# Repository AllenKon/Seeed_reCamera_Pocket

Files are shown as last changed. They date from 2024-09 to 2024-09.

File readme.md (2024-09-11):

**The project contains the 3D housing and circuit design files of the reCamera Pocket.**

🎈🎈🎈🎈🎈🎈🎈🎈🎈

## reCamera Pocket



The reCamera Pocket is a portable charging device for reCamera, available in two models, vertical and horizontal.

The STL file for printing is at the URL: https://makerworld.com/zh/models/634900

Picture should be here.

### Horizontal

Horizontal compatible with standard version of reCamera.

### Vertical

Vertical needs to be replaced with a B2 base plate and replace the retainers on the bottom of the reCamera.

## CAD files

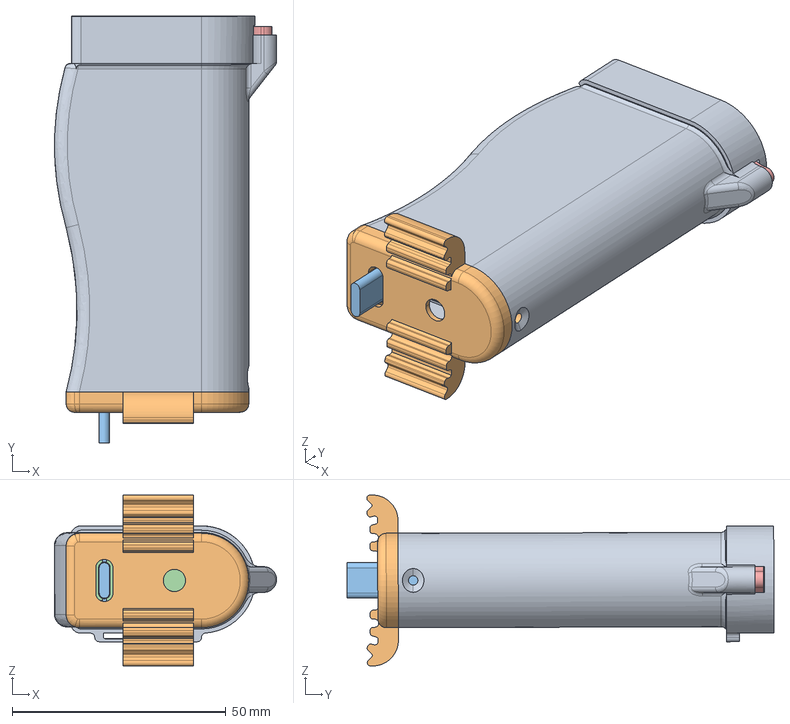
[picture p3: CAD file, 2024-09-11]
Model/reCamera_Pocket_Horizontal.stp
52.0 x 99.9 x 40.0 mm
BATTERY_SHELL
TOP_SHELL
TYPEC_BOARD
4000MAH_BATTERY
BOTTOM_SHELL

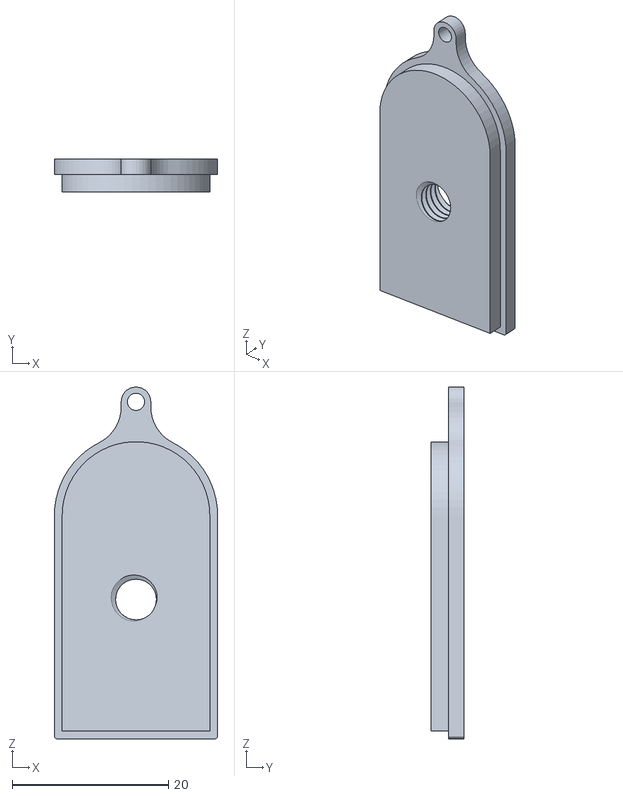
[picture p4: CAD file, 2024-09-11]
STL/reCamera_Pocket_Shell_Bottom.stl
20.9 x 4.20 x 45.1

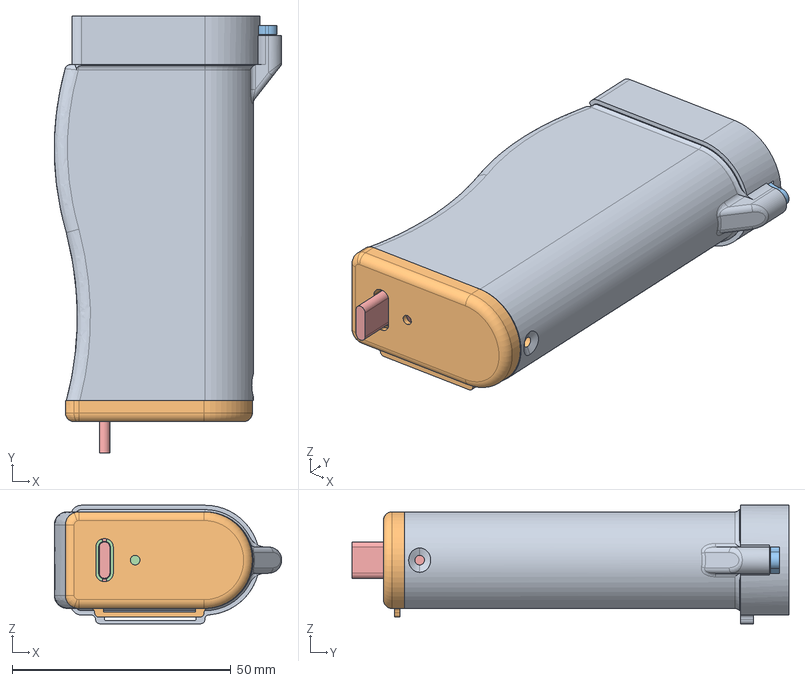
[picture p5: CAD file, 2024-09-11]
Model/reCamera_Pocket_Vertical.stp
52.0 x 99.9 x 27.1 mm
BATTERY_SHELL
VERTICAL_SHELL
BOTTOM_SHELL
4000MAH_BATTERY
TYPEC_BOARD

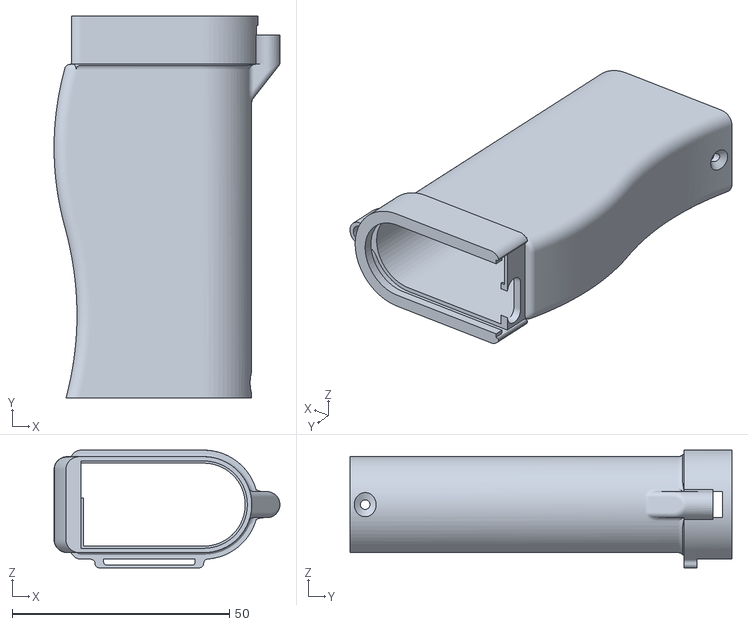
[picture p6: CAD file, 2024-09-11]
STL/reCamera_Pocket_Shell_V.stl
52.0 x 87.9 x 27.1

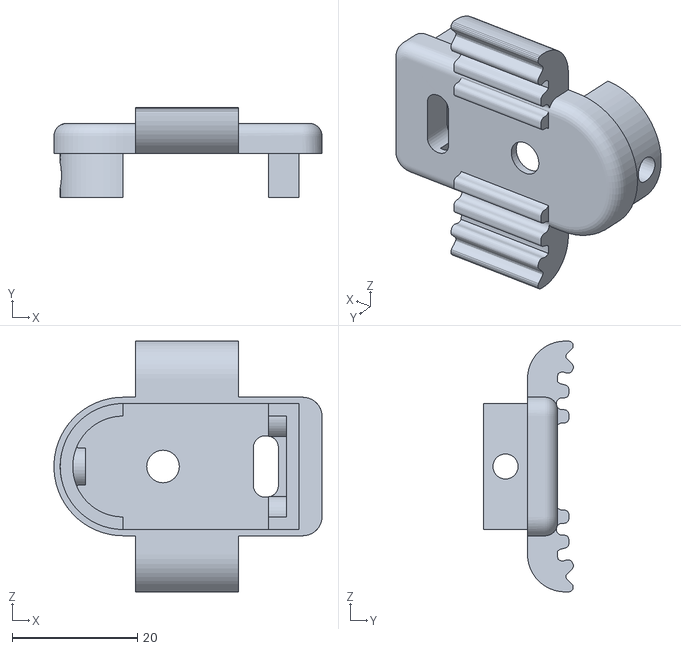
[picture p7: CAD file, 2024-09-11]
STL/reCamera_Pocket_Shell_Top_H.stl
42.7 x 14.3 x 40.0

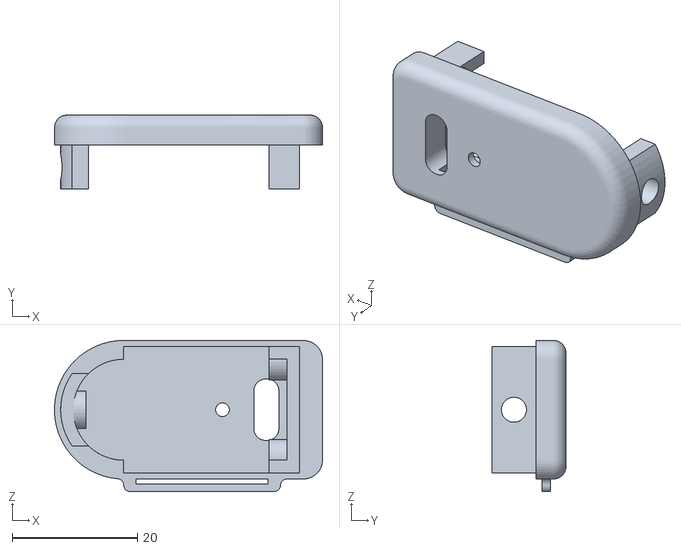
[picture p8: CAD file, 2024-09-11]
STL/reCamera_Pocket_Shell_Top_V.stl
42.7 x 11.8 x 24.1

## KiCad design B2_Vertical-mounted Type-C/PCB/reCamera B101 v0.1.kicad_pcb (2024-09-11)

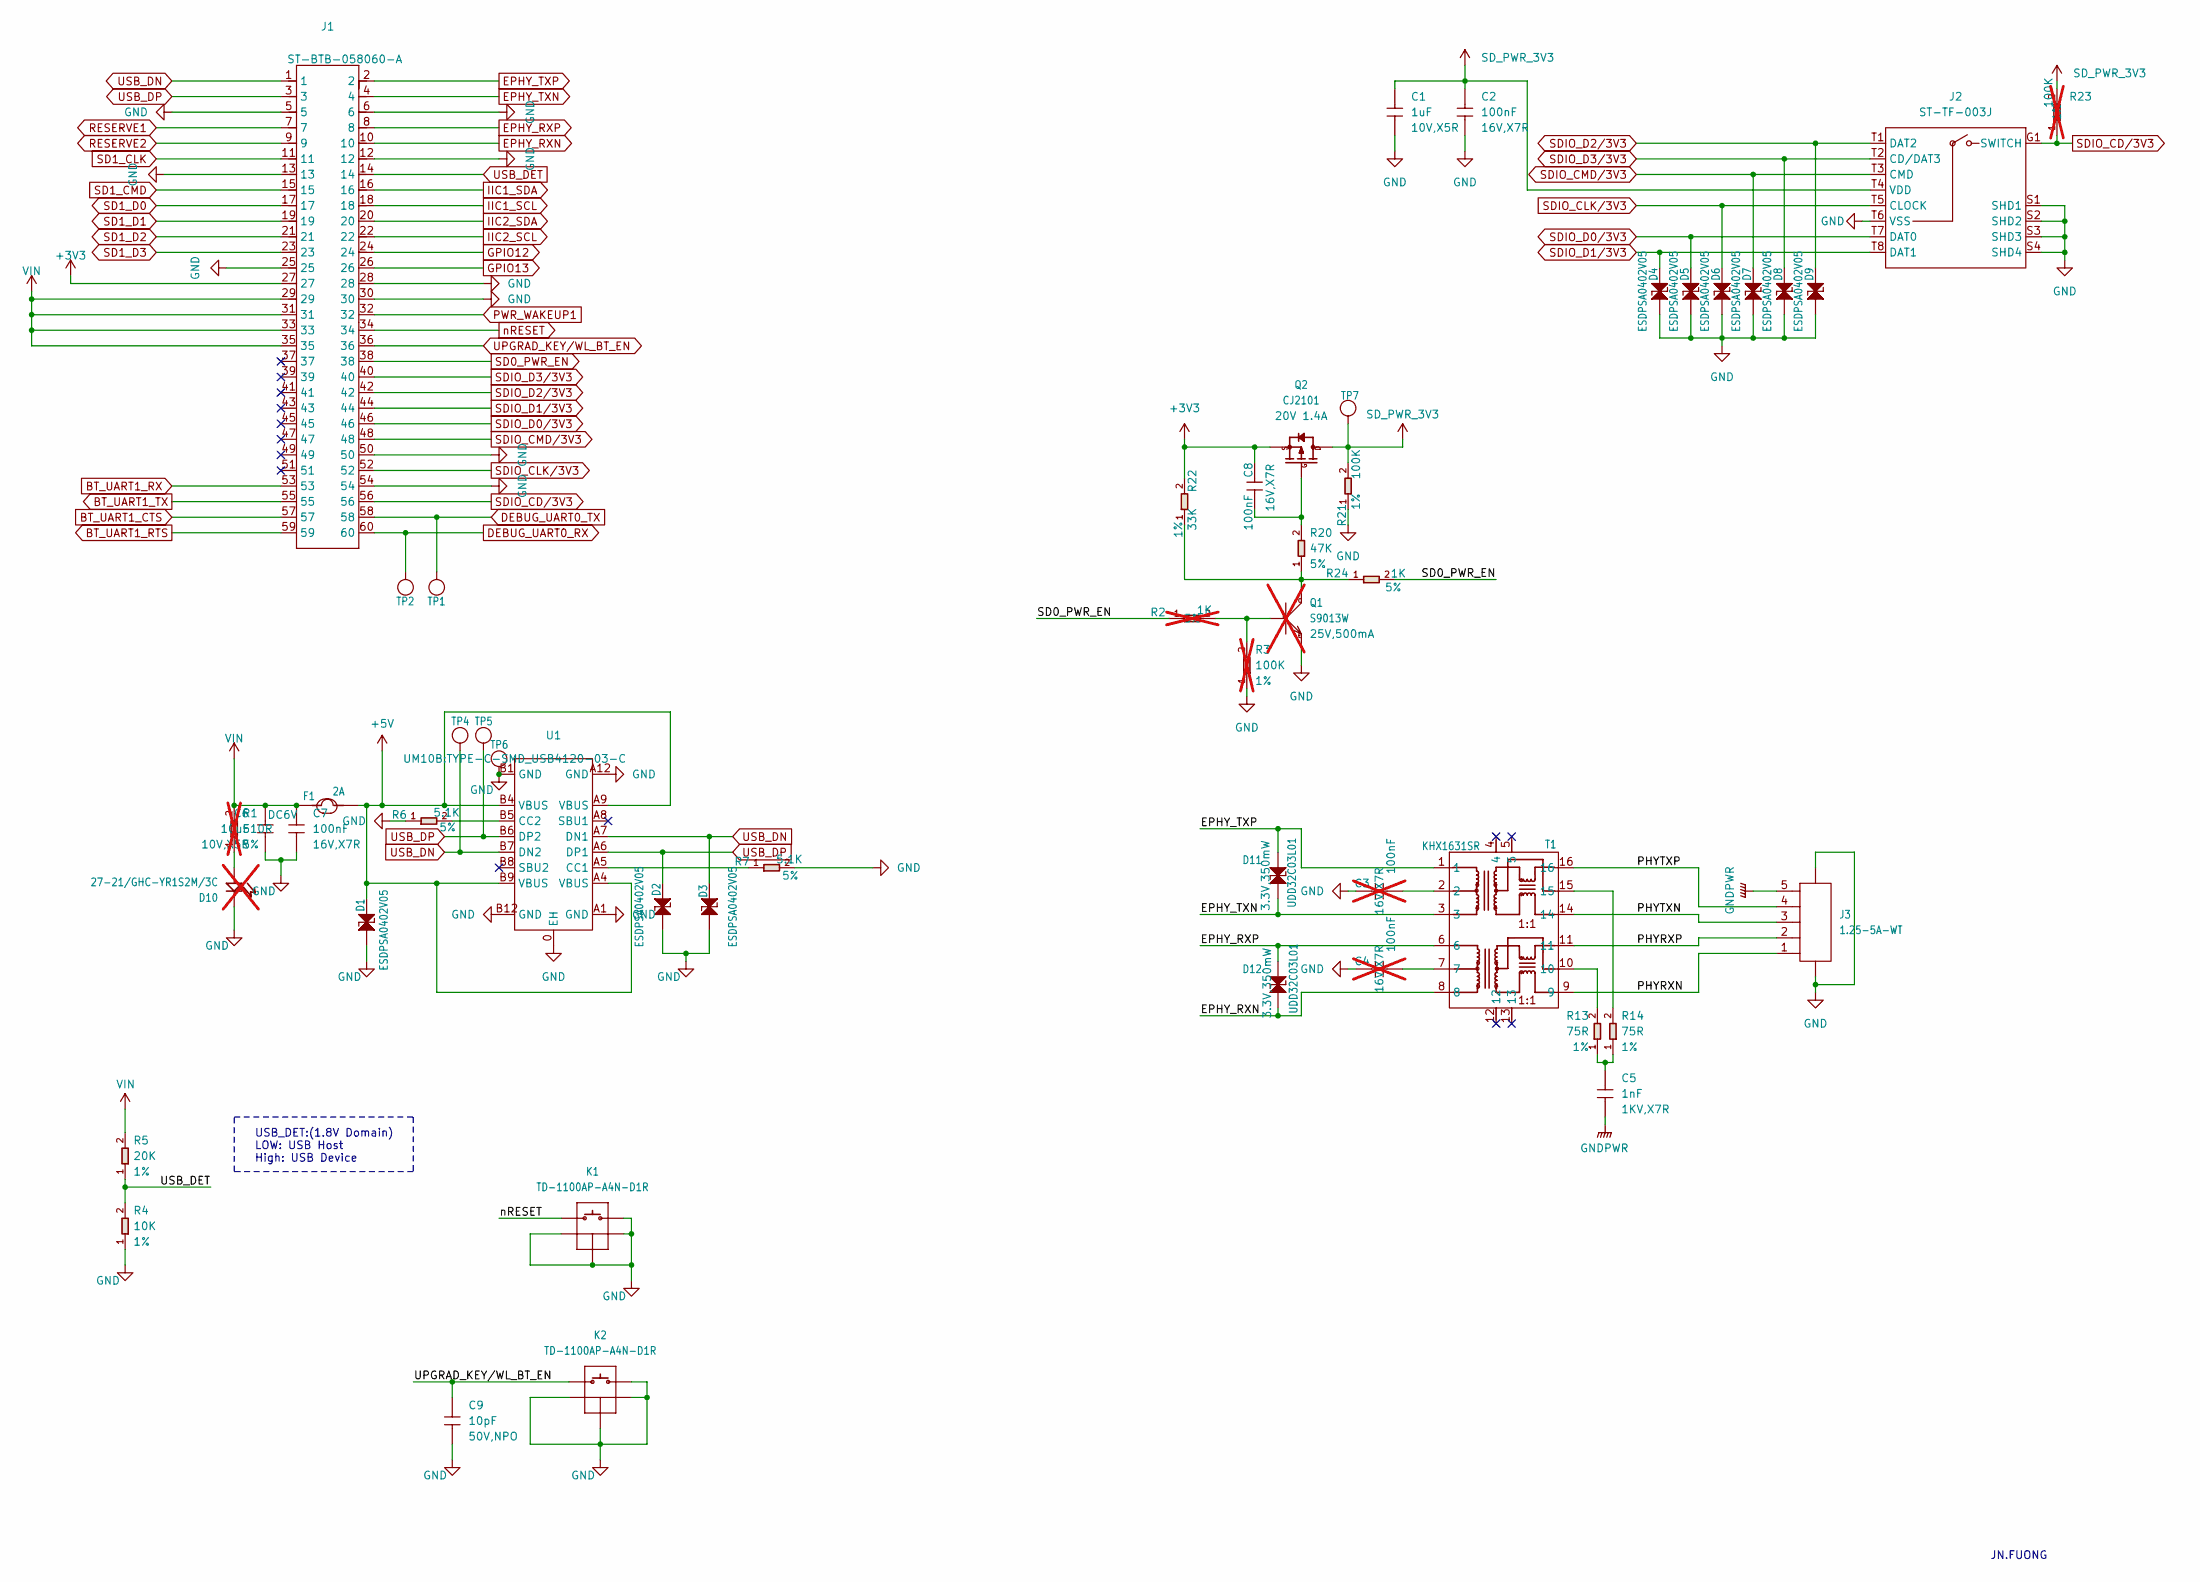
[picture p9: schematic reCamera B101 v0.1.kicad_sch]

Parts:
C1: 1uF; C0402; Voltage Rating 10V,X5R; MPN CC0402KRX5R6BB105
C2, C7, C8: 100nF; C0402; Voltage Rating 16V,X7R; MPN CC0402KRX7R7BB104
C3, C4: 100nF; C0402; Voltage Rating 16V,X7R; MPN CC0402KRX7R7BB104; not fitted
C5: 1nF; C1206; Voltage Rating 1KV,X7R; MPN CC1206KKX7RCBB102
C6: 10uF; C0603; Voltage Rating 10V,X5R; MPN CC0603KRX5R6BB106
C9: 10pF; C0402; Voltage Rating 50V,NPO; MPN CC0402JRNPO9BN100
D1, D2, D3, D4, D5, D6, D7, D8, D9: ESDPSA0402V05; ESD-0402; MPN ESDPSA0402V05
D10: 27-21/GHC-YR1S2M/3C; LED2-0.6X1.7MM; MPN 27-21/GHC-YR1S2M/3C; not fitted
D11, D12: UDD32C03L01; SOD-323; Rating 3.3V,350mW; MPN UDD32C03L01
F1: 2A; F1210; Rating DC6V; MPN SMD1210R200SF
J1: ST-BTB-058060-A; BTB60-Male-Female-0.5-17.7x4.4mm; MPN ST-BTB-058060-A
J2: ST-TF-003J; MICRO-SD-CARD-9P; MPN ST-TF-003J
J3: 1.25-5A-WT; JST5_2P_1d25_7_9x4_3x3_4mm; MPN 1.25-5A-WT
K1, K2: TD-1100AP-A4N-D1R; SW5-SMD-4.56X2.3X1.9MM; MPN TD-1100AP-A4N-D1R
Q1: S9013W; SOT-323; Rating 25V,500mA; MPN S9013W; not fitted
Q2: CJ2101; SOT-323; Rating 20V 1.4A; MPN CJ2101
R1: 510R; R0402; Power Rating 5%; MPN RC0402JR-07510RL; not fitted
R2: 1K; R0402; Power Rating 5%; MPN RC0402JR-071KL; not fitted
R3, R23: 100K; R0402; Power Rating 1%; MPN RC0402FR-07100KL; not fitted
R4: 10K; R0402; Power Rating 1%; MPN RC0402FR-0710KL
R5: 20K; R0402; Power Rating 1%; MPN RC0402FR-0720KL
R6, R7: 5.1K; R0402; Power Rating 5%; MPN RC0402JR-075K1L
R13, R14: 75R; R0603; Power Rating 1%; MPN RC0603FR-0775RL
R20: 47K; R0402; Power Rating 5%; MPN RC0402JR-0747KL
R21: 100K; R0402; Power Rating 1%; MPN RC0402FR-07100KL
R22: 33K; R0402; Power Rating 1%; MPN RC0402FR-0733KL
R24: 1K; R0402; Power Rating 5%; MPN RC0402JR-071KL
T1: KHX1631SR; TRF_16p_1d27_12d7x7d15x5d1mm; MPN KHX1631SR
TP1, TP2, TP4, TP5, TP6, TP7: Test Point; TP-D35MIL; Part Type Test Point
U1: TYPE-C-SMD_USB4120-03-C

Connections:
+3V3: C8.1, J1.27, Q2.2 (S), R22.2
+5V: D1.1, F1.2, U1.A4 (VBUS), U1.A9 (VBUS), U1.B4 (VBUS), U1.B9 (VBUS)
/PHYRXN: J3.1, T1.9
/PHYRXP: J3.2, T1.11
/PHYTXN: J3.3, T1.14
/PHYTXP: J3.4, T1.16
BT_UART1_CTS: J1.57
BT_UART1_RTS: J1.59
BT_UART1_RX: J1.53
BT_UART1_TX: J1.55
DEBUG_UART0_RX: J1.60, TP2.1 (T)
DEBUG_UART0_TX: J1.58, TP1.1 (T)
EPHY_RXN: D12.1, J1.10, T1.8
EPHY_RXP: D12.2, J1.8, T1.6
EPHY_TXN: D11.1, J1.4, T1.3
EPHY_TXP: D11.2, J1.2, T1.1
GNDPWR: C5.2, J3.5
GPIO12: J1.24
GPIO13: J1.26
IIC1_SCL: J1.18
IIC1_SDA: J1.16
IIC2_SCL: J1.22
IIC2_SDA: J1.20
unnamed: C3.2, T1.2
unnamed: C4.2, T1.7
unnamed: C5.1, R13.1, R14.1
unnamed: D10.1 (+), R1.1
unnamed: Q1.1 (B), R2.2, R3.2
unnamed: Q1.3 (C), R20.1, R22.1, R24.1
unnamed: C8.2, Q2.1 (G), R20.2
unnamed: R13.2, T1.10
unnamed: R14.2, T1.15
unnamed: R7.1, U1.A5 (CC1)
PWR_WAKEUP1: J1.32
RESERVE1: J1.7
RESERVE2: J1.9
SD0_PWR_EN: J1.38, R2.1, R24.2
SD1_CLK: J1.11
SD1_CMD: J1.15
SD1_D0: J1.17
SD1_D1: J1.19
SD1_D2: J1.21
SD1_D3: J1.23
SDIO_CD/3V3: J1.56, J2.G1 (SWITCH), R23.1
SDIO_CLK/3V3: D6.1, J1.52, J2.T5 (CLOCK)
SDIO_CMD/3V3: D7.1, J1.48, J2.T3 (CMD)
SDIO_D0/3V3: D5.1, J1.46, J2.T7 (DAT0)
SDIO_D1/3V3: D4.1, J1.44, J2.T8 (DAT1)
SDIO_D2/3V3: D9.1, J1.42, J2.T1 (DAT2)
SDIO_D3/3V3: D8.1, J1.40, J2.T2 (CD/DAT3)
SD_PWR_3V3: C1.1, C2.1, J2.T4 (VDD), Q2.3 (D), R21.2, R23.2, TP7.1 (T)
UPGRAD_KEY/WL_BT_EN: C9.1, J1.36, K2.1
USB_DET: J1.14, R4.2, R5.1
USB_DN: D3.1, J1.1, TP4.1 (T), U1.A7 (DN1), U1.B7 (DN2)
USB_DP: D2.1, J1.3, TP5.1 (T), U1.A6 (DP1), U1.B6 (DP2)
VIN: C6.1, C7.1, F1.1, J1.29, J1.31, J1.33, J1.35, R1.2, R5.2
nRESET: J1.34, K1.1

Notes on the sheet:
JN.FUONG
USB_DET:(1.8V Domain) LOW: USB Host High: USB Device

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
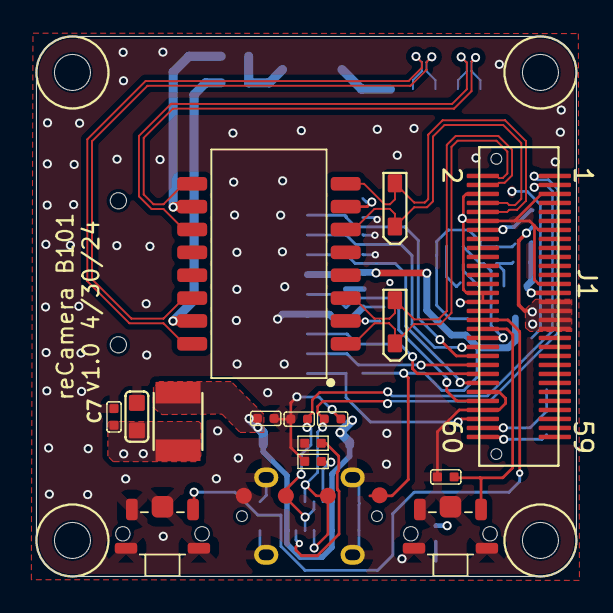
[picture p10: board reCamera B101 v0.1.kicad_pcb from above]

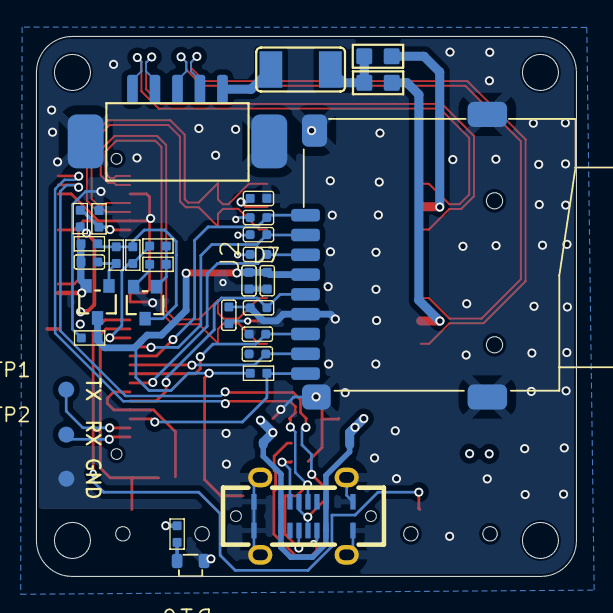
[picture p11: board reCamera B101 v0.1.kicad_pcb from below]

Board: 4 copper layers, 30.0 x 30.0 mm, 51 parts (32 on the bottom side), 40 nets.
